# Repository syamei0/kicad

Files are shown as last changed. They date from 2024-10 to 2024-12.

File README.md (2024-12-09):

power_suplly_v3.1.0

⚠注意⚠　　
リレーの逆起電力対策がされていません。　　
ダイオードを外付けして使用してください。　　

入力は12V  
出力  
12V×7(合計20Aまで)  
5V×8(3.3V出力と合わせて合計1.5Aまで)  
3.3V×8(合計800mAまで)  

LEDの抵抗値変えたら24V入力もできるかも  
その場合12V系統は無くなるけど　　

左下のDIPスイッチで非常停止ボタン押したときに切る系統を変更可能  


パーツ
https://partscabi.net/list/3c4d911b-a046-48f9-8f62-2c7ad6c0e181

ESP32_SMD_v2.1.0  
esp32-wroom-32e用の基板です。

仕様　　  
・圧電スピーカーは0ピン　  
・CANはTXDが5ピン、RXDが4ピン　　  
・JP3とJP4はcanの終端抵抗　　  
・上バー付の数字はPWM可　　  
・白抜き文字は書き込み中プルアップ　　  

3D ビューアー 2024_12_01 20_32_58
パーツ(コンデンサー類未入力)
https://partscabi.net/list/7565f6eb-4755-48bc-bd06-0c08493c0ea4

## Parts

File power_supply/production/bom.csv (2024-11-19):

Designator | Footprint | Quantity | Value | LCSC Part #
C1 | CP_Radial_D10.0mm_P5.00mm | 1 | C_Polarized
C5, C7 | 0603 | 2 | 1μF
C6, C8 | 0603 | 2 | 0.1μF
D1, D2, D3 | 0603 | 3 | LED
D4 | 0603 | 1 | OSHR1608C1A
D5 | D_SOD-123F | 1 | GS1010FL
D6, D7, D8 | D_SOD-123F | 3 | D
F1, F2, F3, F4, F5, F6, F7 | 3557-15_KEY | 7 | Fuse
J1 | AMASS_XT60-M_1x02_P7.20mm_Vertical | 1 | XT60_IN
J10, J11, J12, J13, J14, J15, J16, J9 | JST_XH_B2B-XH-A_1x02_P2.50mm_Vertical | 8 | XH_OUT
J17, J18, J19, J20, J21, J22, J23, J24 | JST_XH_B2B-XH-A_1x02_P2.50mm_Vertical | 8 | XH_3.3V_OUT
J2 | JST_XH_B2B-XH-A_1x02_P2.50mm_Vertical | 1 | Emergency Stop Switch
J25, J3, J4, J5, J6, J7, J8 | AMASS_XT60-F_1x02_P7.20mm_Vertical | 7 | XT60_OUT
Q1 | TO-252-3_TabPin2 | 1 | TTC014
R1, R2, R3, R4, R6 | 0603 | 5 | 10kΩ
R5 | 0603 | 1 | 1kΩ
SW1 | KSD42 | 1 | SW_DIP_x04
U1 | TO-252-3_TabPin2 | 1 | NJM7805SDL1
U2 | TO-252-3_TabPin2 | 1 | NJM2845DL1-33
U3 | 953-1C-12DG-1 | 1 | 953-1C-12DG-1
U4, U5 | 134-1C-12DS | 2 | 134-1C-12DS

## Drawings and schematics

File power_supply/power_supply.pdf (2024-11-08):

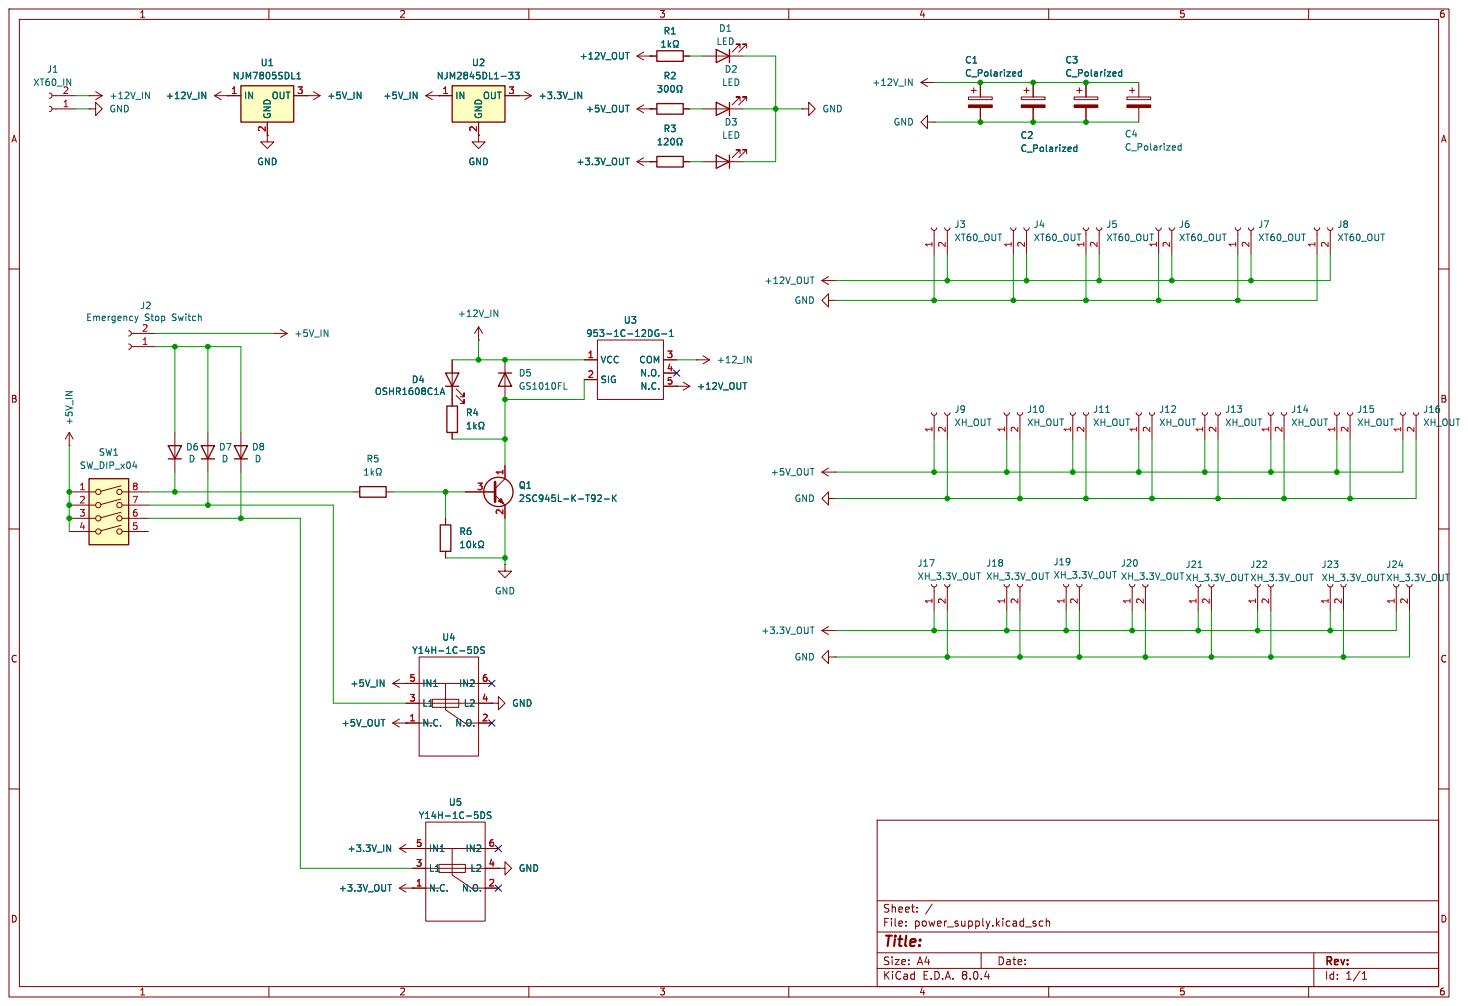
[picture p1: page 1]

Id: 1/1 Title: File: power_supply.kicad_sch Sheet: /

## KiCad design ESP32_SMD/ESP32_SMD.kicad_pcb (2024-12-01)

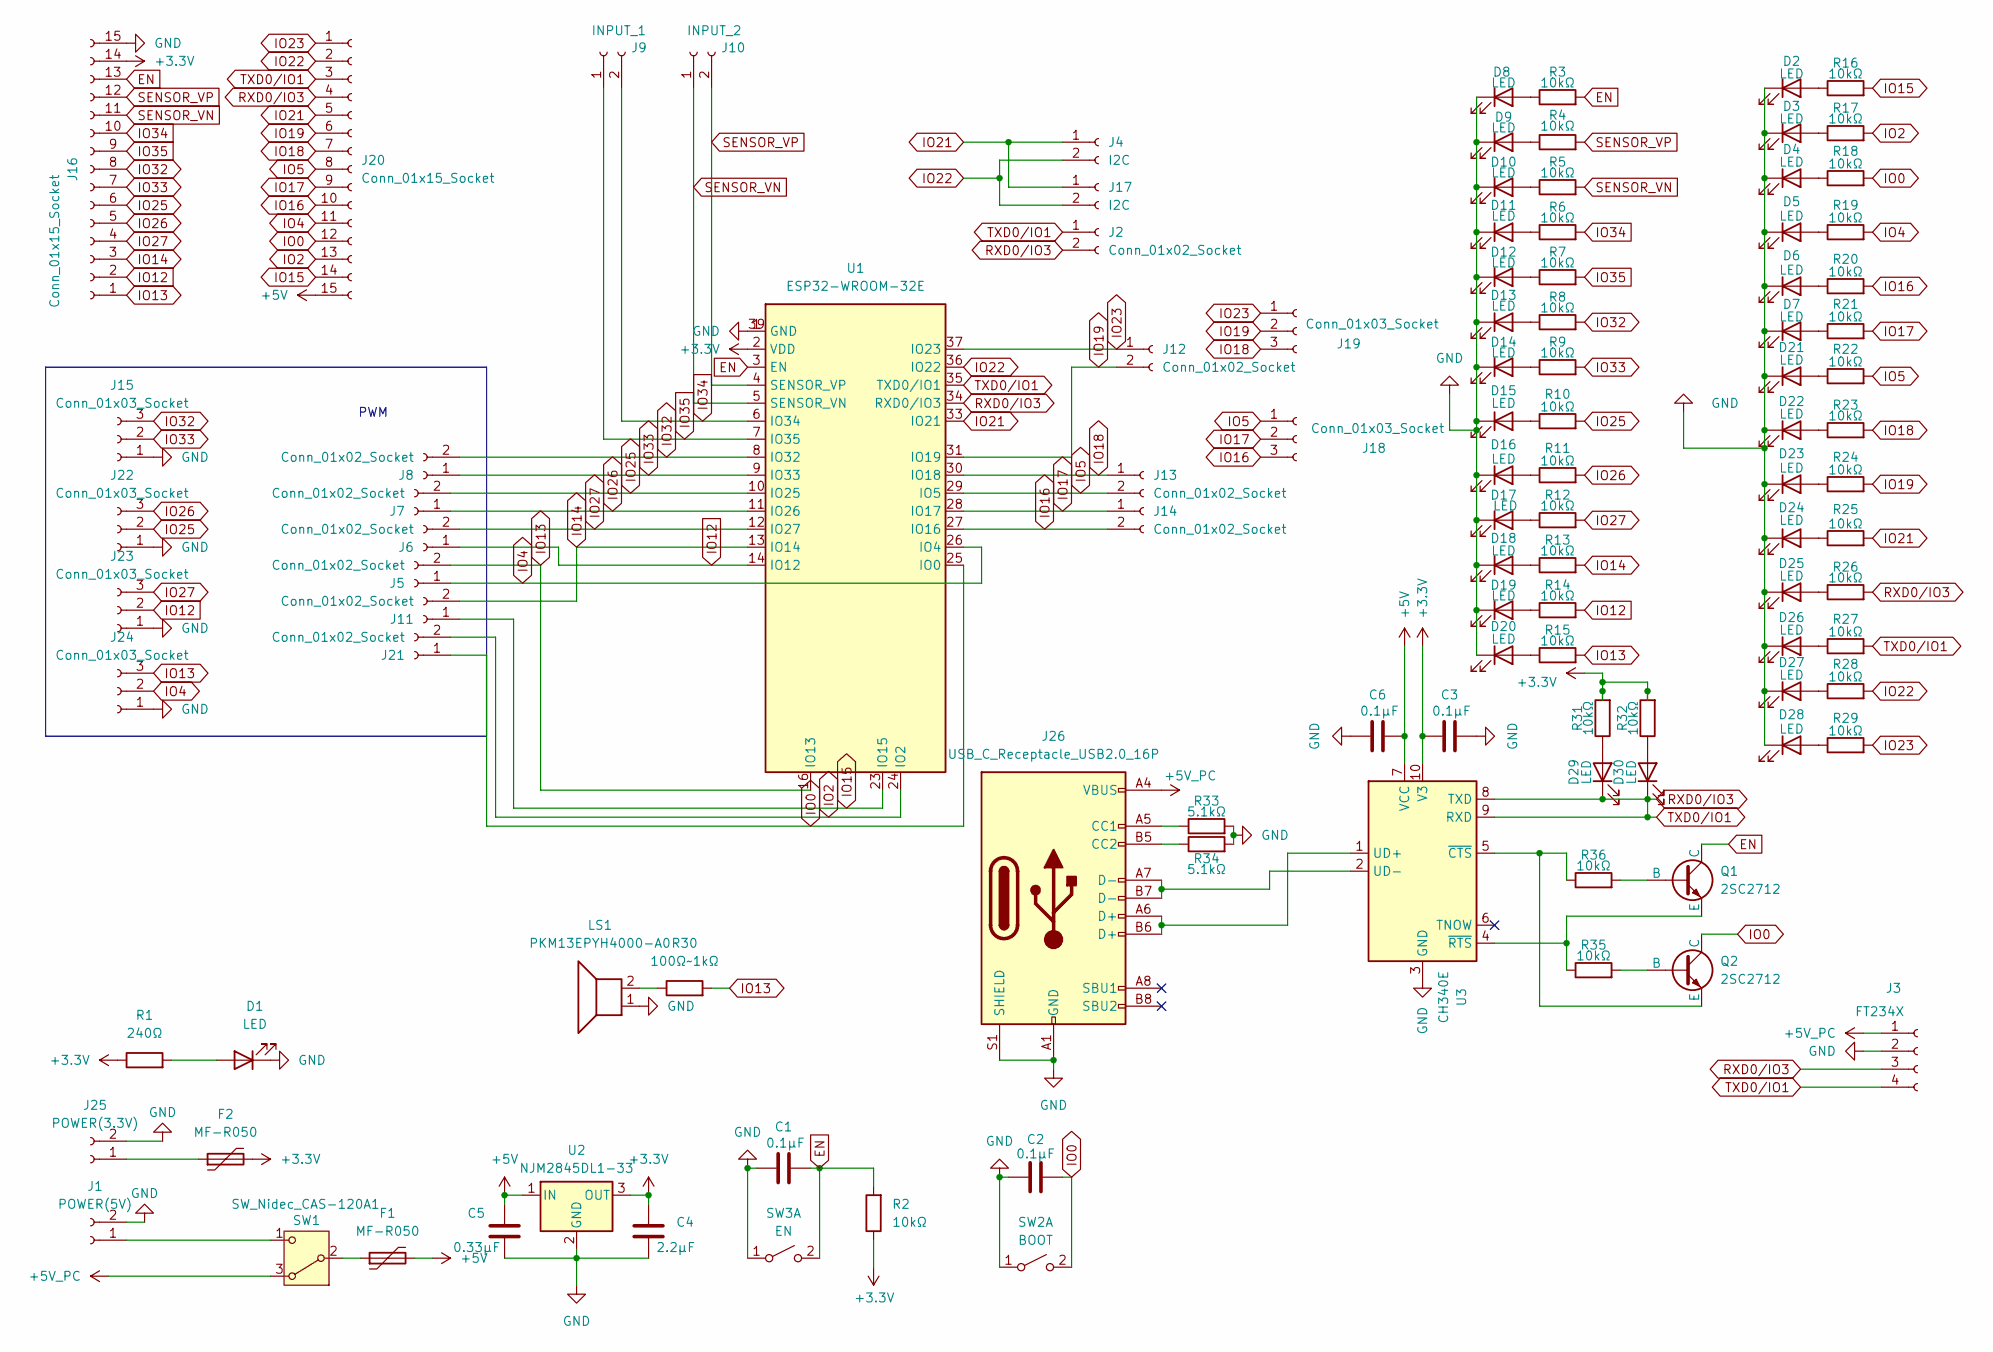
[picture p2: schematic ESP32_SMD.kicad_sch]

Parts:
C1, C2, C3, C6: 0.1μF; C_0603_1608Metric_Pad1.08x0.95mm_HandSolder
C4: 2.2μF; C_0603_1608Metric_Pad1.08x0.95mm_HandSolder
C5: 0.33μF; C_0603_1608Metric_Pad1.08x0.95mm_HandSolder
D1: LED; LED_0603_1608Metric
D2, D3, D4, D5, D6, D7, D8, D9, D10, D11, D12, D13, D14, D15, D16, D17, D18, D19, D20, D21, D22, D23, D24, D25, D26, D27, D28, D29, D30: LED; LED_0603_1608Metric_Pad1.05x0.95mm_HandSolder
F1, F2: MF-R050
J1: POWER(5V); JST_XH_B2B-XH-A_1x02_P2.50mm_Vertical
J2, J5, J6, J7, J8, J11, J12, J13, J14, J21: Conn_01x02_Socket; JST_XH_B2B-XH-A_1x02_P2.50mm_Vertical
J3: FT234X; PinHeader_1x04_P2.54mm_Vertical
J4, J17: I2C; JST_XH_B2B-XH-A_1x02_P2.50mm_Vertical
J9: INPUT_1; JST_XH_B2B-XH-A_1x02_P2.50mm_Vertical
J10: INPUT_2; JST_XH_B2B-XH-A_1x02_P2.50mm_Vertical
J15, J18, J19, J22, J23, J24: Conn_01x03_Socket; JST_XH_B3B-XH-A_1x03_P2.50mm_Vertical
J16, J20: Conn_01x15_Socket; PinHeader_1x15_P2.54mm_Vertical
J25: POWER(3.3V); JST_XH_B2B-XH-A_1x02_P2.50mm_Vertical
J26: USB_C_Receptacle_USB2.0_16P; USB_C_Receptacle_GCT_USB4105-xx-A_16P_TopMnt_Horizontal
LS1: PKM13EPYH4000-A0
Q1, Q2: 2SC2712; SOT-23
R1: 240Ω; R_0603_1608Metric_Pad0.98x0.95mm_HandSolder
R2, R3, R4, R5, R6, R7, R8, R9, R10, R11, R12, R13, R14, R15, R16, R17, R18, R19, R20, R21, R22, R23, R24, R25, R26, R27, R28, R29, R31, R32, R35, R36: 10kΩ; R_0603_1608Metric_Pad0.98x0.95mm_HandSolder
R30: 100Ω~1kΩ; R_0603_1608Metric_Pad0.98x0.95mm_HandSolder
R33, R34: 5.1kΩ; R_0603_1608Metric_Pad0.98x0.95mm_HandSolder
SW1: SW_Nidec_CAS-120A1; TerminalBlock_Xinya_XY308-2.54-3P_1x03_P2.54mm_Horizontal
SW2: BOOT; DTS-63-N-V
SW3: EN; DTS-63-N-V
U1: ESP32-WROOM-32E
U2: NJM2845DL1-33; TO-252-3_TabPin2
U3: CH340E; MSOP-10_3x3mm_P0.5mm

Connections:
+3.3V: C3.2, C4.2, F2.2, J16.14, R1.1, R2.1, R31.2, R32.2, U1.2 (VDD), U2.3 (OUT), U3.10 (V3)
+5V: C5.2, C6.1, F1.2, J20.15, U2.1 (IN), U3.7 (VCC)
+5V_PC: J3.1 (5V), J26.A4 (VBUS), J26.A9 (VBUS), J26.B4 (VBUS), J26.B9 (VBUS), SW1.3 (A)
EN: C1.1, J16.13, Q1.1 (C), R2.2, R3.2, SW3.2 (B), U1.3 (EN)
GND: C1.2, C2.2, C3.1, C4.1, C5.1, C6.2, D1.1 (K), D2.1 (K), D3.1 (K), D4.1 (K), D5.1 (K), D6.1 (K), D7.1 (K), D8.1 (K), D9.1 (K), D10.1 (K), D11.1 (K), D12.1 (K), D13.1 (K), D14.1 (K), D15.1 (K), D16.1 (K), D17.1 (K), D18.1 (K), D19.1 (K), D20.1 (K), D21.1 (K), D22.1 (K), D23.1 (K), D24.1 (K), D25.1 (K), D26.1 (K), D27.1 (K), D28.1 (K), J1.2, J3.2 (GND), J15.1, J16.15, J22.1, J23.1, J24.1, J25.2, J26.A1 (GND), J26.A12 (GND), J26.B1 (GND), J26.B12 (GND), J26.S1 (SHIELD), LS1.1, R33.2, R34.2, SW2.1 (A), SW3.1 (A), U1.1 (GND), U1.15 (GND), U1.38 (GND), U1.39 (GND), U2.2 (GND), U3.3 (GND)
IO0: C2.1, J20.12, J21.1, Q2.1 (C), R18.2, SW2.2 (B), U1.25 (IO0)
IO2: J20.13, J21.2, R17.2, U1.24 (IO2)
IO4: J5.1, J20.11, J24.2, R19.2, U1.26 (IO4)
IO5: J13.2, J18.1, J20.8, R22.2, U1.29 (IO5)
IO12: J6.1, J16.2, J23.2, R14.2, U1.14 (IO12)
IO13: J5.2, J16.1, J24.3, R15.2, R30.2, U1.16 (IO13)
IO14: J11.2, J16.3, R13.2, U1.13 (IO14)
IO15: J11.1, J20.14, R16.2, U1.23 (IO15)
IO16: J14.2, J18.3, J20.10, R20.2, U1.27 (IO16)
IO17: J14.1, J18.2, J20.9, R21.2, U1.28 (IO17)
IO18: J13.1, J19.3, J20.7, R23.2, U1.30 (IO18)
IO19: J12.2, J19.2, J20.6, R24.2, U1.31 (IO19)
IO21: J4.1, J17.1, J20.5, R25.2, U1.33 (IO21)
IO22: J4.2, J17.2, J20.2, R28.2, U1.36 (IO22)
IO23: J12.1, J19.1, J20.1, R29.2, U1.37 (IO23)
IO25: J7.2, J16.6, J22.2, R10.2, U1.10 (IO25)
IO26: J7.1, J16.5, J22.3, R11.2, U1.11 (IO26)
IO27: J6.2, J16.4, J23.3, R12.2, U1.12 (IO27)
IO32: J8.2, J15.3, J16.8, R8.2, U1.8 (IO32)
IO33: J8.1, J15.2, J16.7, R9.2, U1.9 (IO33)
IO34: J9.2, J16.10, R6.2, U1.6 (IO34)
IO35: J9.1, J16.9, R7.2, U1.7 (IO35)
unnamed: D1.2 (A), R1.2
unnamed: D2.2 (A), R16.1
unnamed: D3.2 (A), R17.1
unnamed: D4.2 (A), R18.1
unnamed: D5.2 (A), R19.1
unnamed: D6.2 (A), R20.1
unnamed: D7.2 (A), R21.1
unnamed: D8.2 (A), R3.1
unnamed: D9.2 (A), R4.1
unnamed: D10.2 (A), R5.1
unnamed: D11.2 (A), R6.1
unnamed: D12.2 (A), R7.1
unnamed: D13.2 (A), R8.1
unnamed: D14.2 (A), R9.1
unnamed: D15.2 (A), R10.1
unnamed: D16.2 (A), R11.1
unnamed: D17.2 (A), R12.1
unnamed: D18.2 (A), R13.1
unnamed: D19.2 (A), R14.1
unnamed: D20.2 (A), R15.1
unnamed: D21.2 (A), R22.1
unnamed: D22.2 (A), R23.1
unnamed: D23.2 (A), R24.1
unnamed: D24.2 (A), R25.1
unnamed: D25.2 (A), R26.1
unnamed: D26.2 (A), R27.1
unnamed: D27.2 (A), R28.1
unnamed: D28.2 (A), R29.1
unnamed: D29.2 (A), R31.1
unnamed: D30.2 (A), R32.1
unnamed: J1.1, SW1.1 (C)
unnamed: F2.1, J25.1
unnamed: J26.A5 (CC1), R33.1
unnamed: J26.B5 (CC2), R34.1
unnamed: LS1.2, R30.1
unnamed: Q1.2 (B), R36.2
unnamed: Q1.3 (E), R35.1, U3.4 (~RTS)
unnamed: Q2.2 (B), R35.2
unnamed: Q2.3 (E), R36.1, U3.5 (~CTS)
unnamed: F1.1, SW1.2 (B)
unnamed: J26.A6 (D+), J26.B6 (D+), U3.1 (UD+)
unnamed: J26.A7 (D-), J26.B7 (D-), U3.2 (UD-)
RXD0/IO3: D29.1 (K), D30.1 (K), J2.1, J2.2, J3.3 (TxD), J3.4 (RxD), J20.3, J20.4, R26.2, R27.2, U1.34 (RXD0/IO3), U1.35 (TXD0/IO1), U3.8 (TXD), U3.9 (RXD)
SENSOR_VN: J10.1, J16.11, R5.2, U1.5 (SENSOR_VN)
SENSOR_VP: J10.2, J16.12, R4.2, U1.4 (SENSOR_VP)

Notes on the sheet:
PWM

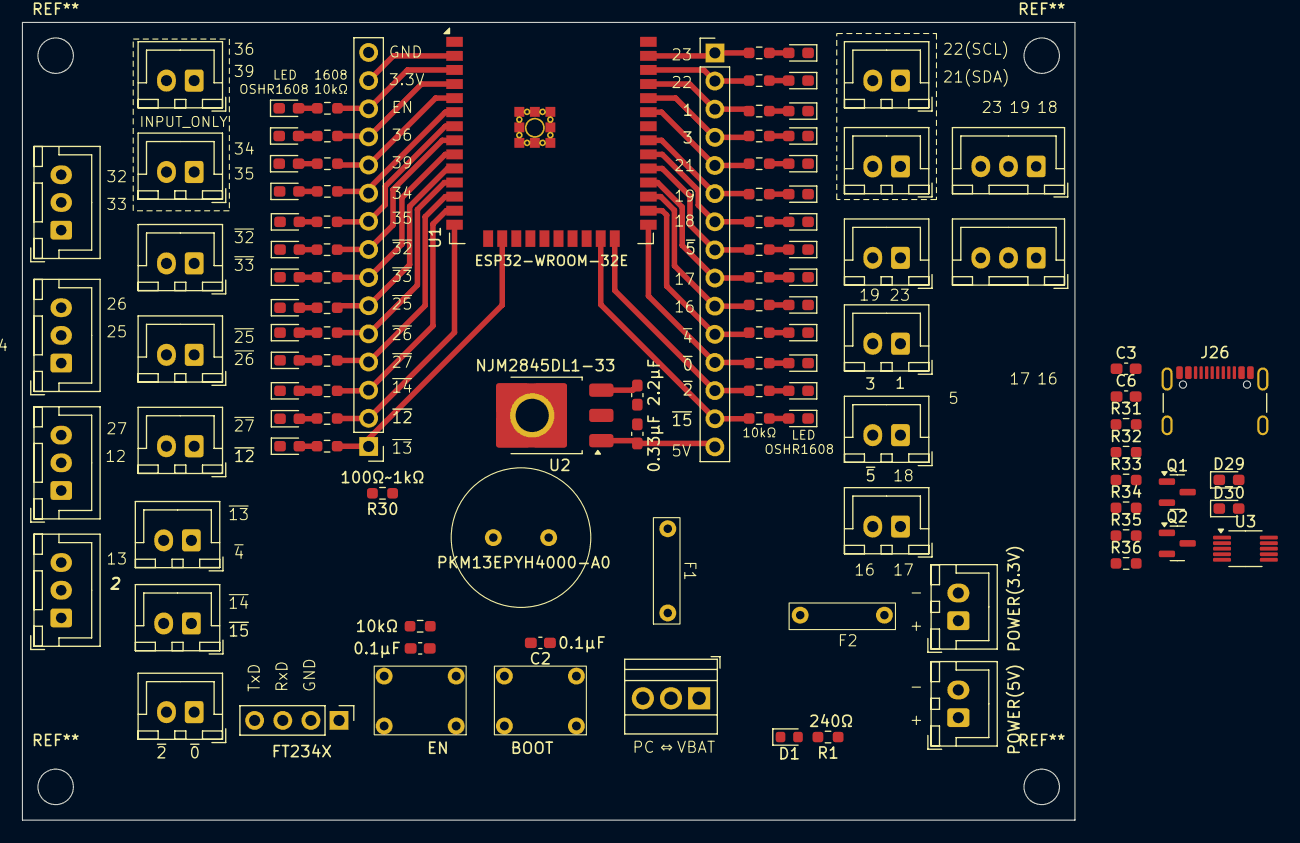
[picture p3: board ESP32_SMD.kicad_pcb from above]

Board: 2 copper layers, 95.0 x 72.0 mm, 109 parts (0 on the bottom side), 72 nets.

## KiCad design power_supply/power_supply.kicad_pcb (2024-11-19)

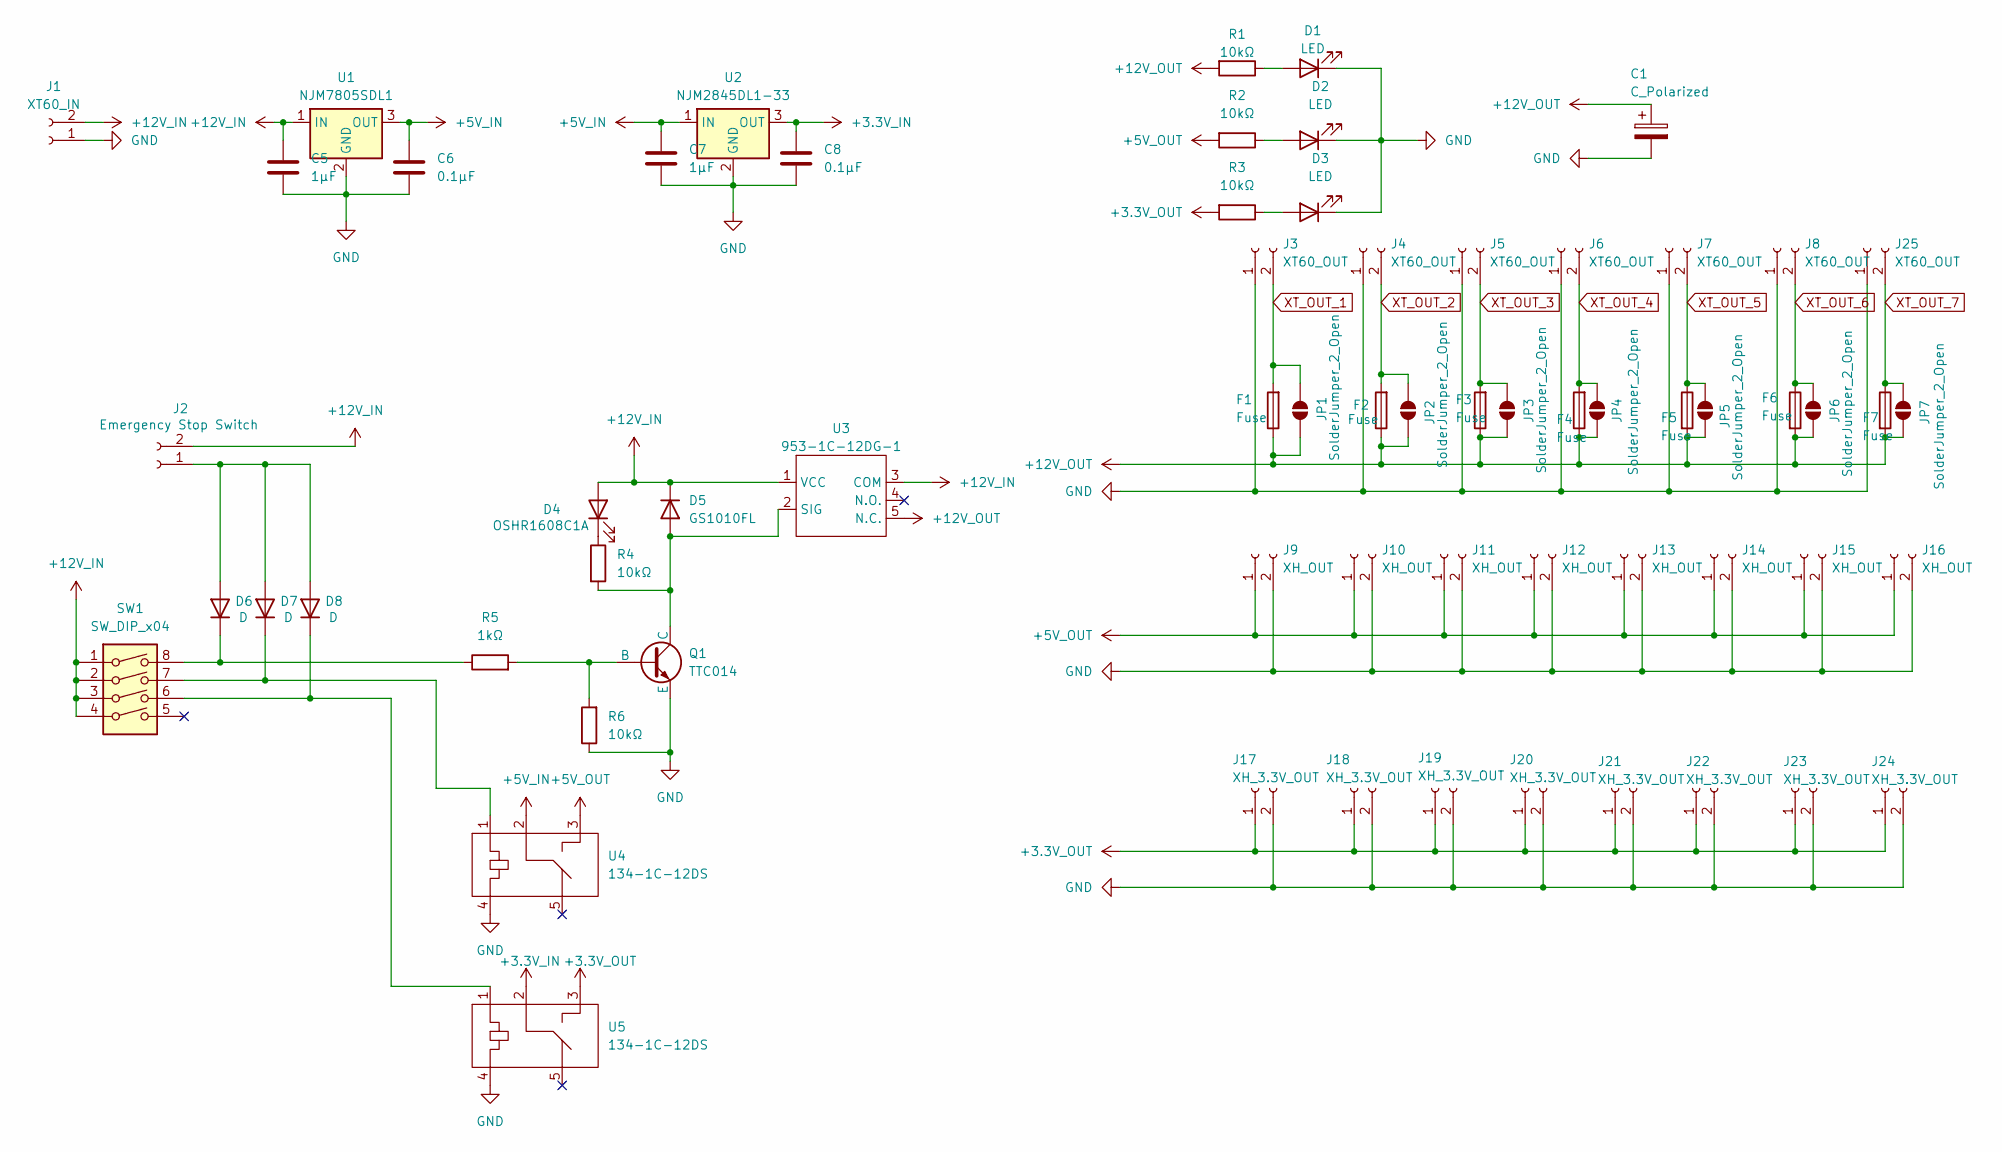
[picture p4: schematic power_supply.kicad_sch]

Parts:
C1: C_Polarized; CP_Radial_D10.0mm_P5.00mm
C5, C7: 1μF; C_0603_1608Metric_Pad1.08x0.95mm_HandSolder
C6, C8: 0.1μF; C_0603_1608Metric_Pad1.08x0.95mm_HandSolder
D1, D2, D3: LED; LED_0603_1608Metric_Pad1.05x0.95mm_HandSolder
D4: OSHR1608C1A; LED_0603_1608Metric_Pad1.05x0.95mm_HandSolder
D5: GS1010FL; D_SOD-123F
D6, D7, D8: D; D_SOD-123F
F1, F2, F3, F4, F5, F6, F7: Fuse; 3557-15_KEY
J1: XT60_IN; AMASS_XT60-M_1x02_P7.20mm_Vertical
J2: Emergency Stop Switch; JST_XH_B2B-XH-A_1x02_P2.50mm_Vertical
J3, J4, J5, J6, J7, J8, J25: XT60_OUT; AMASS_XT60-F_1x02_P7.20mm_Vertical
J9, J10, J11, J12, J13, J14, J15, J16: XH_OUT; JST_XH_B2B-XH-A_1x02_P2.50mm_Vertical
J17, J18, J19, J20, J21, J22, J23, J24: XH_3.3V_OUT; JST_XH_B2B-XH-A_1x02_P2.50mm_Vertical
JP1, JP2, JP3, JP4, JP5, JP6, JP7: SolderJumper_2_Open; SolderJumper-2_P1.3mm_Open_Pad1.0x1.5mm
Q1: TTC014; TO-252-3_TabPin2
R1, R2, R3, R4, R6: 10kΩ; R_0603_1608Metric_Pad0.98x0.95mm_HandSolder
R5: 1kΩ; R_0603_1608Metric_Pad0.98x0.95mm_HandSolder
SW1: SW_DIP_x04; KSD42
U1: NJM7805SDL1; TO-252-3_TabPin2
U2: NJM2845DL1-33; TO-252-3_TabPin2
U3: 953-1C-12DG-1
U4, U5: 134-1C-12DS

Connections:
+3.3V_IN: C8.1, U2.3 (OUT), U5.2
+3.3V_OUT: J17.1, J18.1, J19.1, J20.1, J21.1, J22.1, J23.1, J24.1, R3.2, U5.3
+5V_IN: C6.1, C7.1, U1.3 (OUT), U2.1 (IN), U4.2
+5V_OUT: J9.1, J10.1, J11.1, J12.1, J13.1, J14.1, J15.1, J16.1, R2.2, U4.3
+12V_IN: C5.1, D4.2 (A), D5.1 (K), J1.2, J2.2, SW1.1, SW1.2, SW1.3, SW1.4, U1.1 (IN), U3.1 (VCC), U3.3 (COM)
+12V_OUT: C1.1, F1.1, F2.1, F3.1, F4.1, F5.2, F6.2, F7.2, JP1.1 (A), JP2.1 (A), JP3.1 (A), JP4.1 (A), JP5.1 (A), JP6.1 (A), JP7.1 (A), R1.2, U3.5 (N.C.)
GND: C1.2, C5.2, C6.2, C7.2, C8.2, D1.1 (K), D2.1 (K), D3.1 (K), J1.1, J3.1, J4.1, J5.1, J6.1, J7.1, J8.1, J9.2, J10.2, J11.2, J12.2, J13.2, J14.2, J15.2, J16.2, J17.2, J18.2, J19.2, J20.2, J21.2, J22.2, J23.2, J24.2, J25.1, Q1.3 (E), R6.1, U1.2 (GND), U2.2 (GND), U4.4, U5.4
unnamed: D1.2 (A), R1.1
unnamed: D2.2 (A), R2.1
unnamed: D3.2 (A), R3.1
unnamed: D4.1 (K), R4.1
unnamed: D5.2 (A), Q1.2 (C), R4.2, U3.2 (SIG)
unnamed: D6.2 (A), D7.2 (A), D8.2 (A), J2.1
unnamed: D6.1 (K), R5.1, SW1.8
unnamed: D7.1 (K), SW1.7, U4.1
unnamed: D8.1 (K), SW1.6, U5.1
unnamed: Q1.1 (B), R5.2, R6.2
XT_OUT_1: F1.2, J3.2, JP1.2 (B)
XT_OUT_2: F2.2, J4.2, JP2.2 (B)
XT_OUT_3: F3.2, J5.2, JP3.2 (B)
XT_OUT_4: F4.2, J6.2, JP4.2 (B)
XT_OUT_5: F5.1, J7.2, JP5.2 (B)
XT_OUT_6: F6.1, J8.2, JP6.2 (B)
XT_OUT_7: F7.1, J25.2, JP7.2 (B)

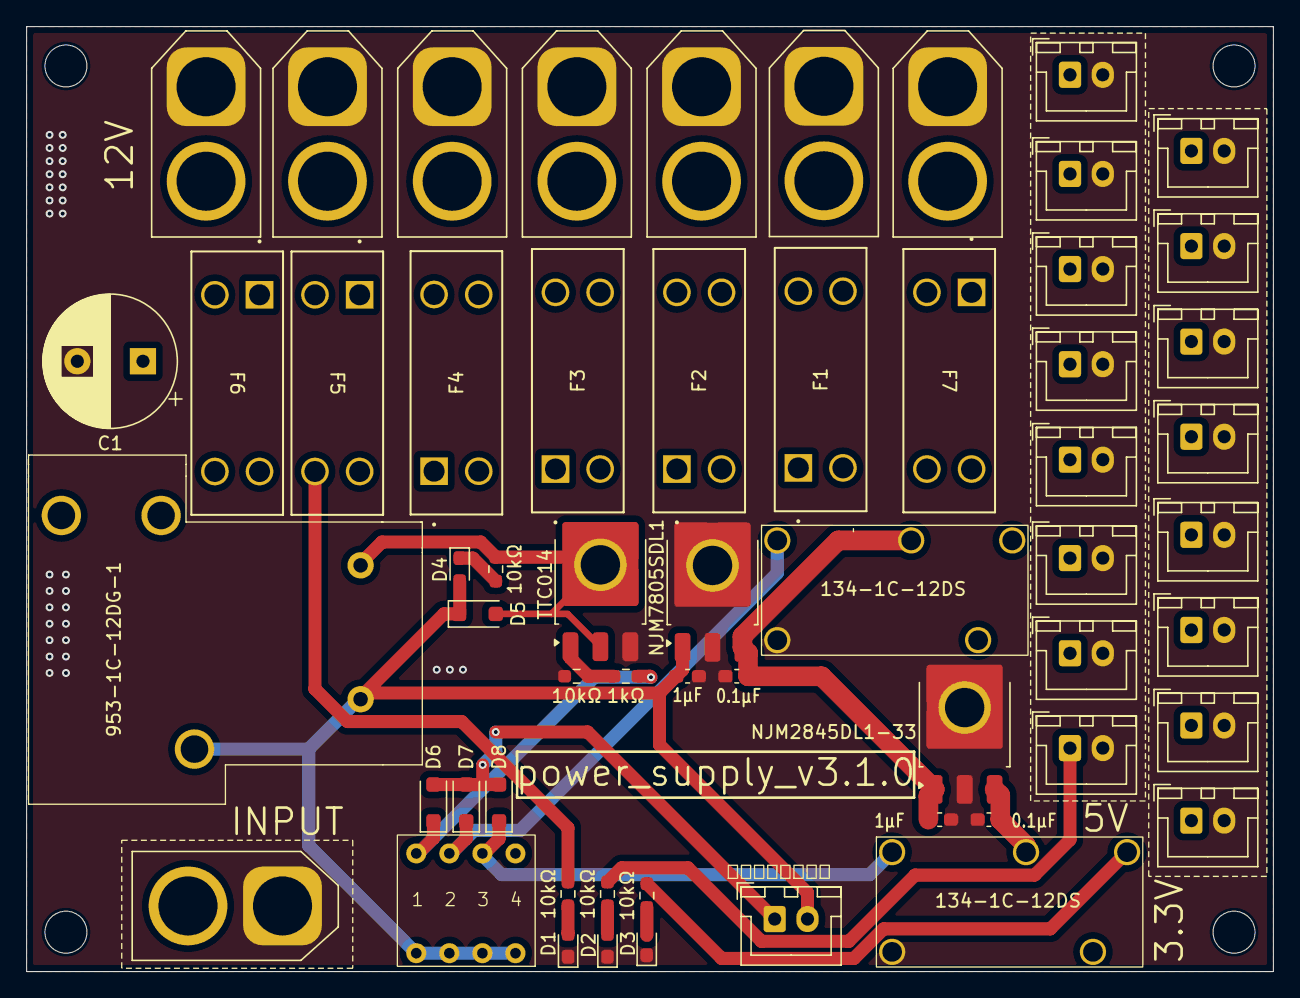
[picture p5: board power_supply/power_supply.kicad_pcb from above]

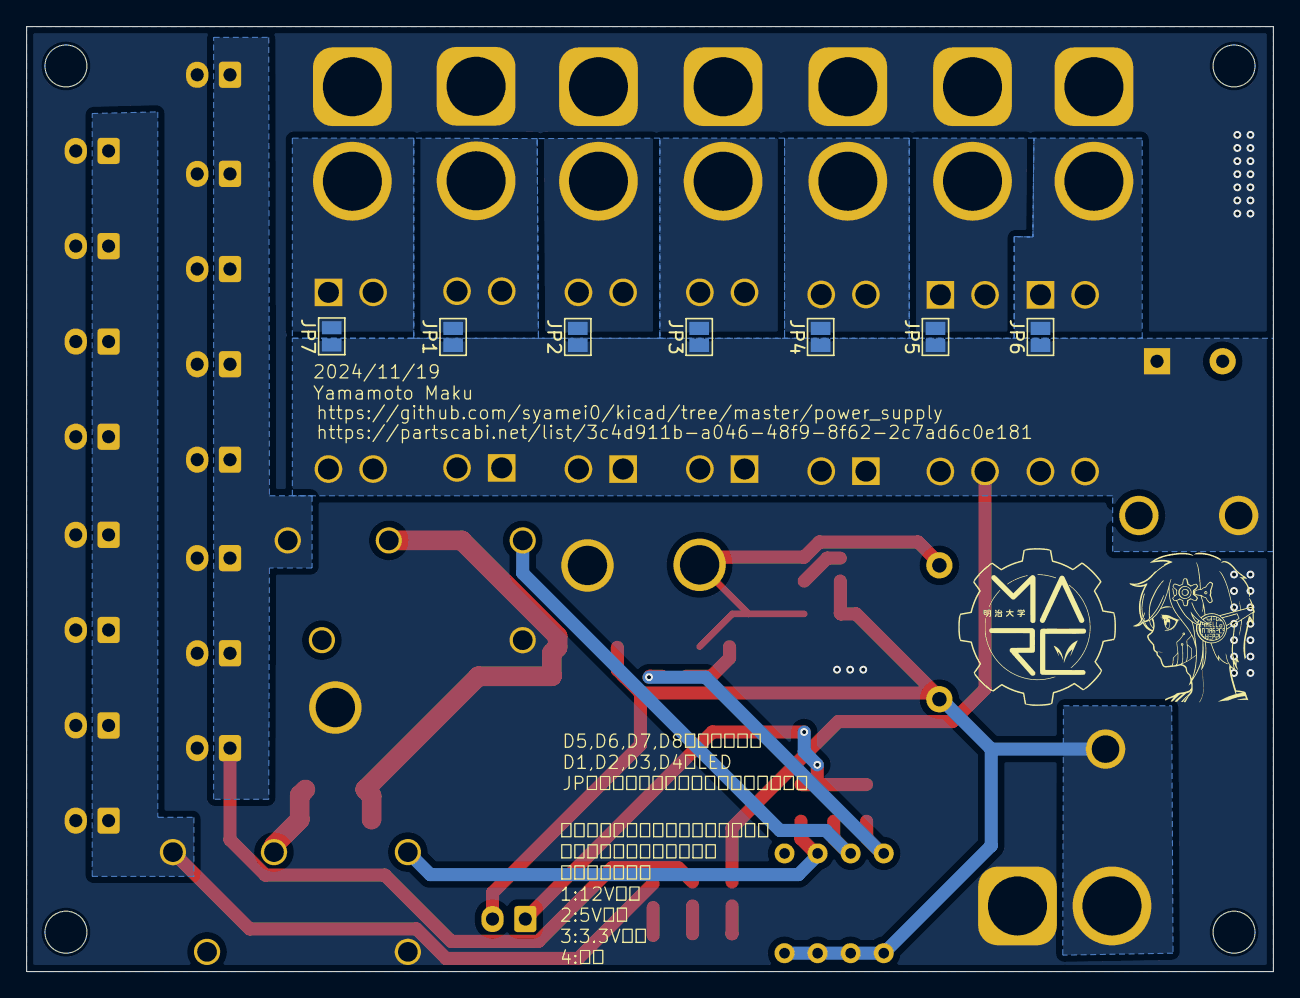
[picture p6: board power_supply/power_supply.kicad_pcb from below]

Board: 2 copper layers, 95.0 x 72.0 mm, 65 parts (7 on the bottom side), 24 nets.

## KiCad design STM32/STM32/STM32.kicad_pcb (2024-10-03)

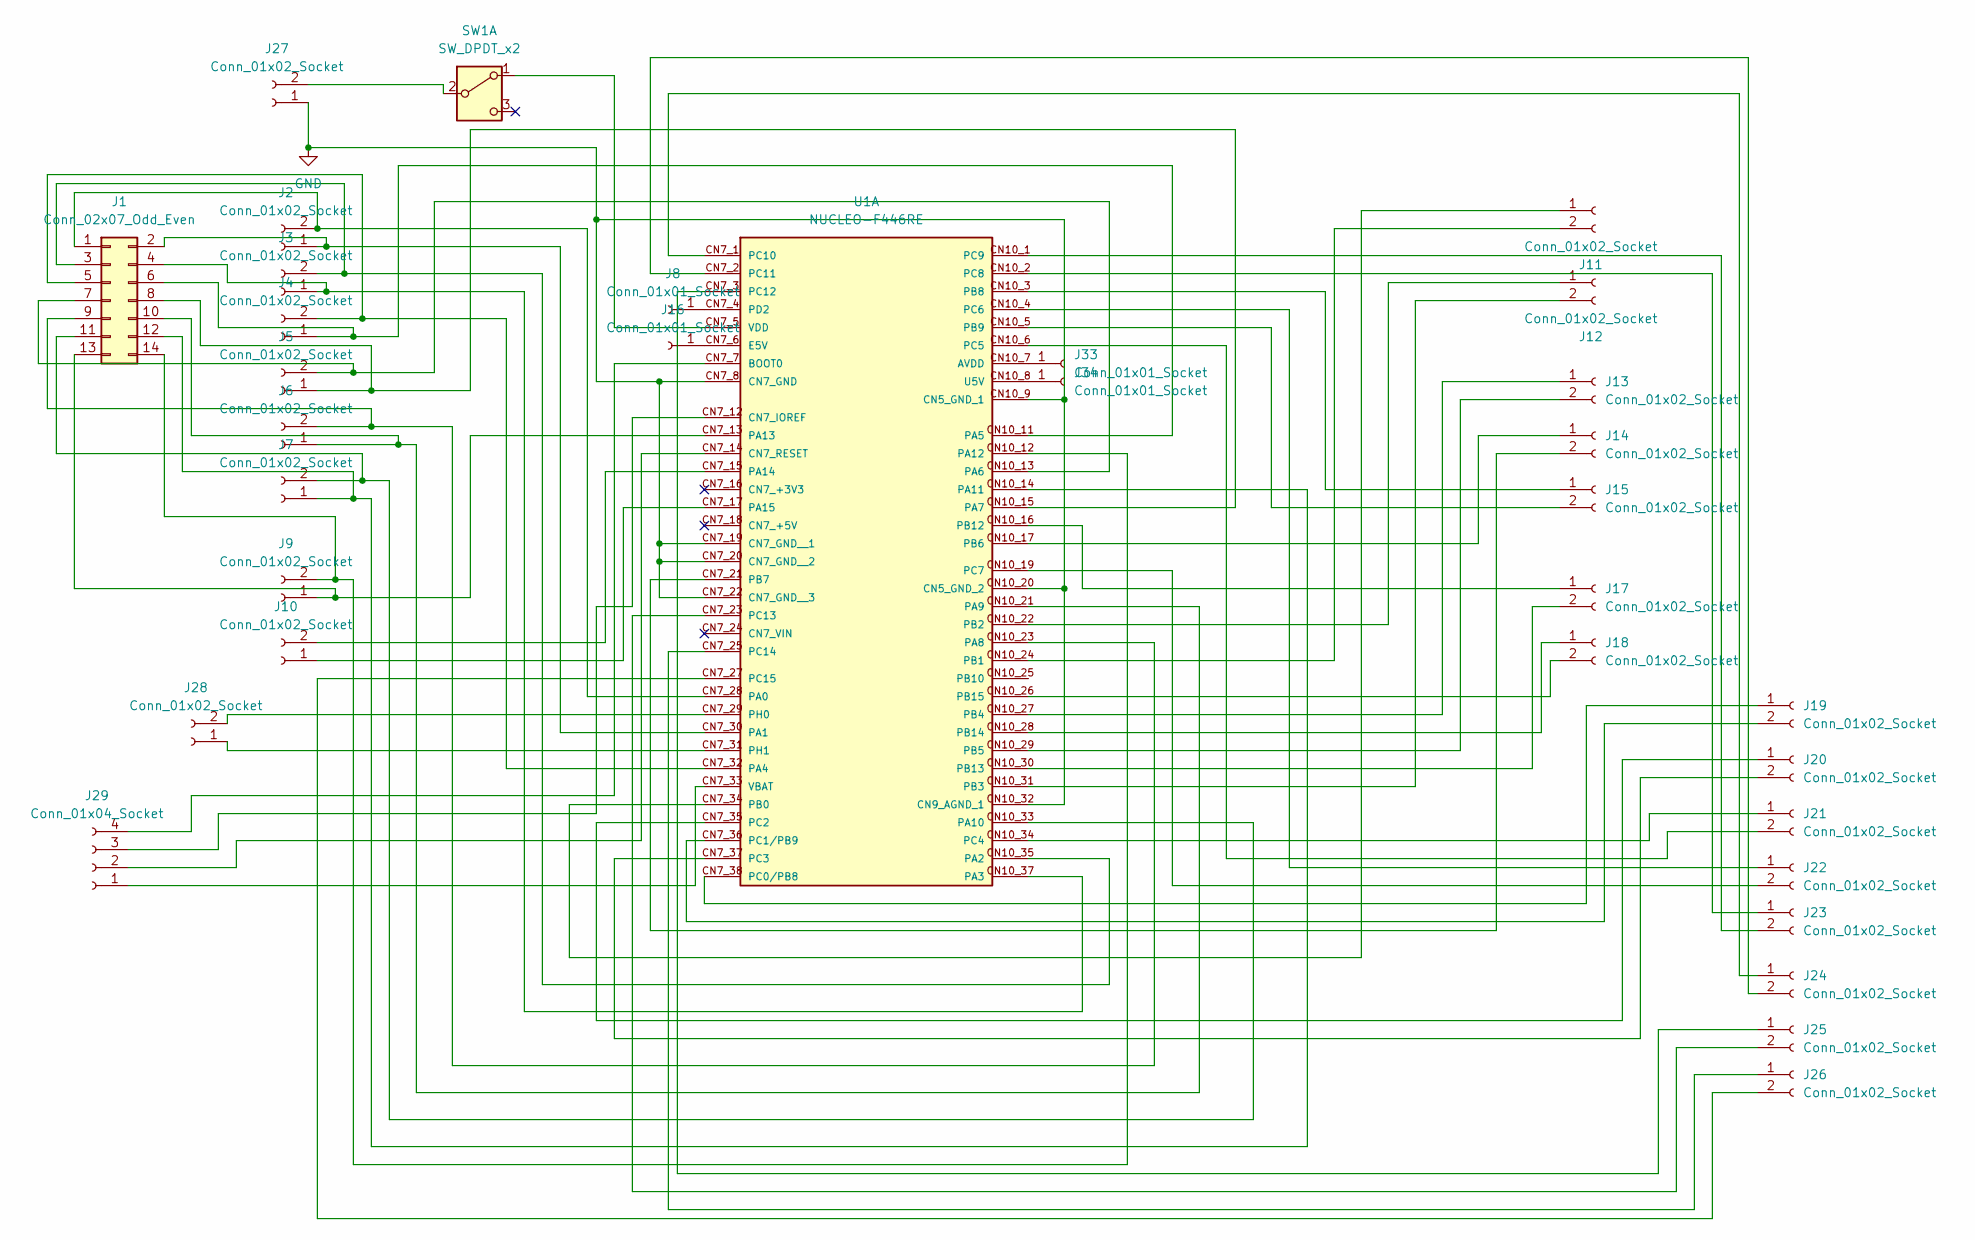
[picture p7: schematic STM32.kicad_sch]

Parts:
J1: Conn_02x07_Odd_Even; PinHeader_2x07_P2.54mm_Vertical
J2, J3, J4, J5, J6, J7, J9, J10, J11, J12, J13, J14, J15, J17, J18, J19, J20, J21, J22, J23, J24, J25, J26, J27, J28: Conn_01x02_Socket; JST_XH_B2B-XH-AM_1x02_P2.50mm_Vertical
J8, J16, J33, J34: Conn_01x01_Socket; JST_XH_B1B-XH-AM_1x01_P2.50mm_Vertical
J29: Conn_01x04_Socket; JST_XH_B4B-XH-AM_1x04_P2.50mm_Vertical
SW1: SW_DPDT_x2; PinHeader_1x03_P2.54mm_Vertical
U1: NUCLEO-F446RE; MODULE_NUCLEO-F446RE; PARTREV 13

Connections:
GND: J27.1, U1.CN7_8 (CN7_GND), U1.CN7_19 (CN7_GND__1), U1.CN7_20 (CN7_GND__2), U1.CN7_22 (CN7_GND__3), U1.CN10_9 (CN5_GND_1), U1.CN10_20 (CN5_GND_2), U1.CN10_32 (CN9_AGND_1)
unnamed: J1.1, J2.2, U1.CN7_28 (PA0)
unnamed: J1.2, J2.1, U1.CN7_30 (PA1)
unnamed: J1.3, J3.2, U1.CN10_35 (PA2)
unnamed: J1.4, J3.1, U1.CN10_37 (PA3)
unnamed: J1.5, J4.2, U1.CN7_32 (PA4)
unnamed: J1.6, J4.1, U1.CN10_11 (PA5)
unnamed: J1.7, J5.2, U1.CN10_13 (PA6)
unnamed: J1.8, J5.1, U1.CN10_15 (PA7)
unnamed: J1.9, J6.2, U1.CN10_23 (PA8)
unnamed: J1.10, J6.1, U1.CN10_21 (PA9)
unnamed: J1.11, J7.2, U1.CN10_33 (PA10)
unnamed: J1.12, J7.1, U1.CN10_14 (PA11)
unnamed: J1.13, J9.1, U1.CN7_13 (PA13)
unnamed: J1.14, J9.2, U1.CN10_12 (PA12)
unnamed: J8.1, U1.CN7_4 (PD2)
unnamed: J10.1, U1.CN7_17 (PA15)
unnamed: J10.2, U1.CN7_15 (PA14)
unnamed: J11.1, U1.CN7_34 (PB0)
unnamed: J11.2, U1.CN10_24 (PB1)
unnamed: J12.1, U1.CN10_22 (PB2)
unnamed: J12.2, U1.CN10_31 (PB3)
unnamed: J13.1, U1.CN10_27 (PB4)
unnamed: J13.2, U1.CN10_29 (PB5)
unnamed: J14.1, U1.CN10_17 (PB6)
unnamed: J14.2, U1.CN7_21 (PB7)
unnamed: J15.1, U1.CN10_3 (PB8)
unnamed: J15.2, U1.CN10_5 (PB9)
unnamed: J16.1, U1.CN7_6 (E5V)
unnamed: J17.1, U1.CN10_16 (PB12)
unnamed: J17.2, U1.CN10_30 (PB13)
unnamed: J18.1, U1.CN10_28 (PB14)
unnamed: J18.2, U1.CN10_26 (PB15)
unnamed: J19.1, U1.CN7_38 (PC0/PB8)
unnamed: J19.2, U1.CN7_36 (PC1/PB9)
unnamed: J20.1, U1.CN7_35 (PC2)
unnamed: J20.2, U1.CN7_37 (PC3)
unnamed: J21.1, U1.CN10_34 (PC4)
unnamed: J21.2, U1.CN10_6 (PC5)
unnamed: J22.1, U1.CN10_4 (PC6)
unnamed: J22.2, U1.CN10_19 (PC7)
unnamed: J23.1, U1.CN10_2 (PC8)
unnamed: J23.2, U1.CN10_1 (PC9)
unnamed: J24.1, U1.CN7_1 (PC10)
unnamed: J24.2, U1.CN7_2 (PC11)
unnamed: J25.1, U1.CN7_3 (PC12)
unnamed: J25.2, U1.CN7_23 (PC13)
unnamed: J26.1, U1.CN7_25 (PC14)
unnamed: J26.2, U1.CN7_27 (PC15)
unnamed: J27.2, SW1.2 (B)
unnamed: J28.1, U1.CN7_31 (PH1)
unnamed: J28.2, U1.CN7_29 (PH0)
unnamed: J29.1, U1.CN7_33 (VBAT)
unnamed: J29.2, U1.CN7_14 (CN7_RESET)
unnamed: J29.3, U1.CN7_12 (CN7_IOREF)
unnamed: J29.4, U1.CN7_7 (BOOT0)
unnamed: J33.1, U1.CN10_7 (AVDD)
unnamed: J34.1, U1.CN10_8 (U5V)
unnamed: SW1.1 (A), U1.CN7_5 (VDD)

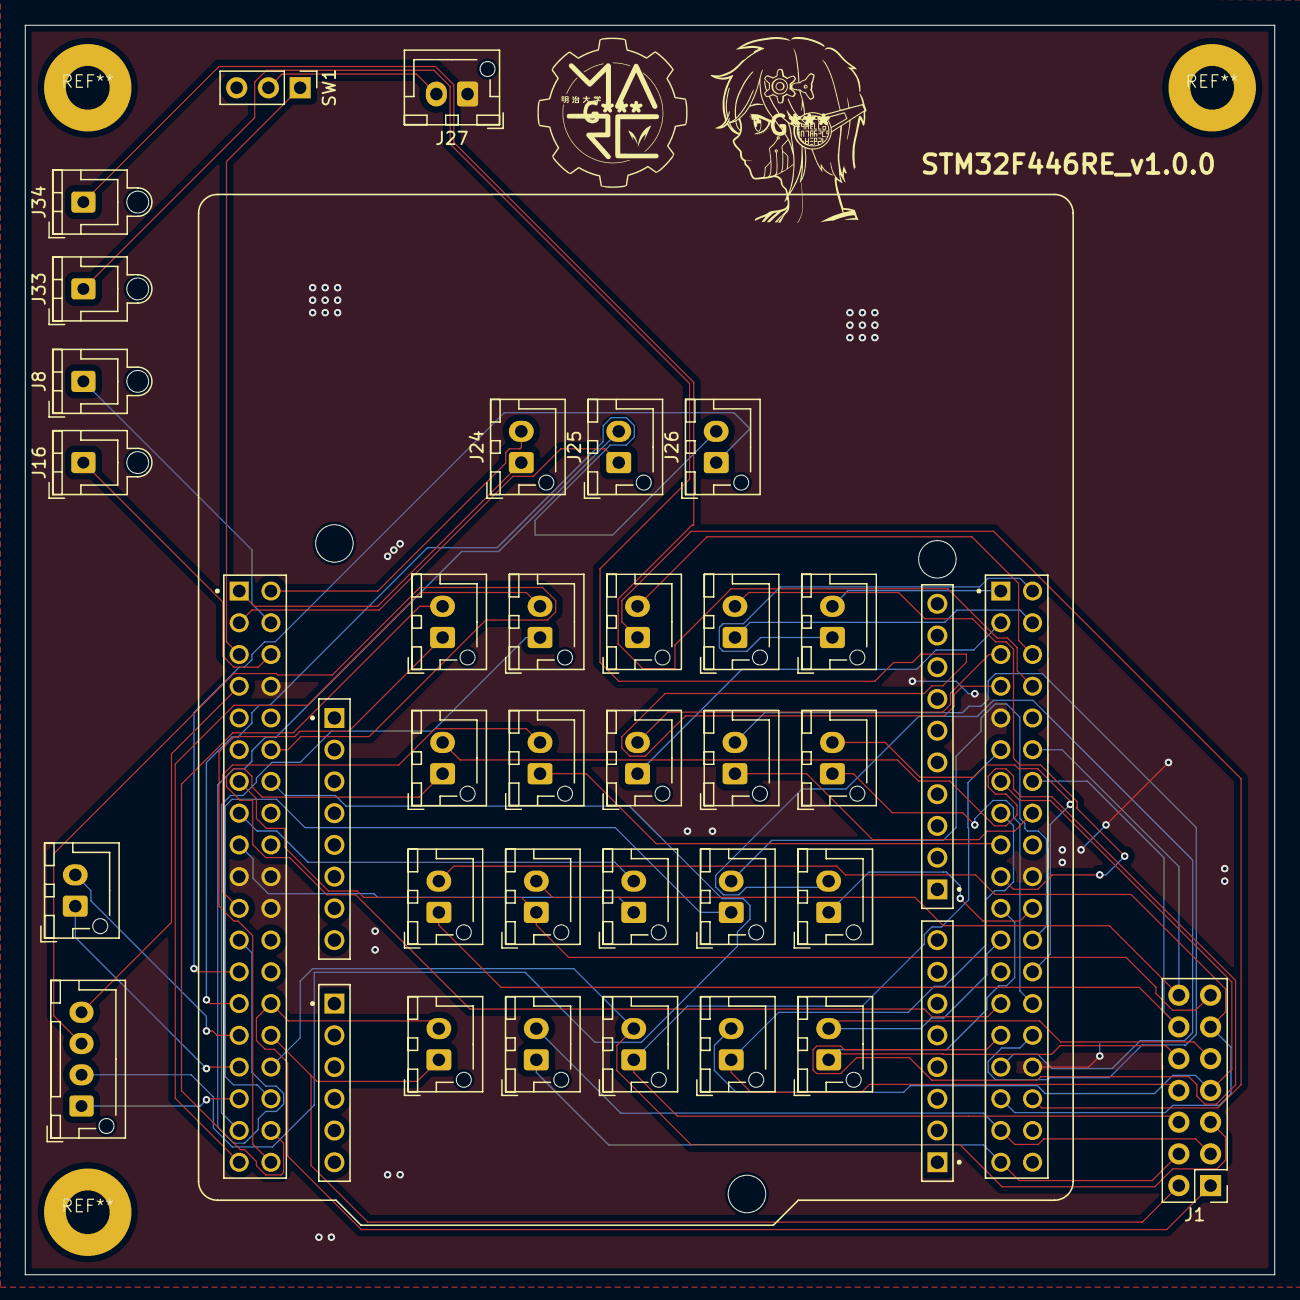
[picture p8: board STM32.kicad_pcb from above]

Board: 2 copper layers, 100.0 x 100.0 mm, 33 parts (0 on the bottom side), 59 nets.

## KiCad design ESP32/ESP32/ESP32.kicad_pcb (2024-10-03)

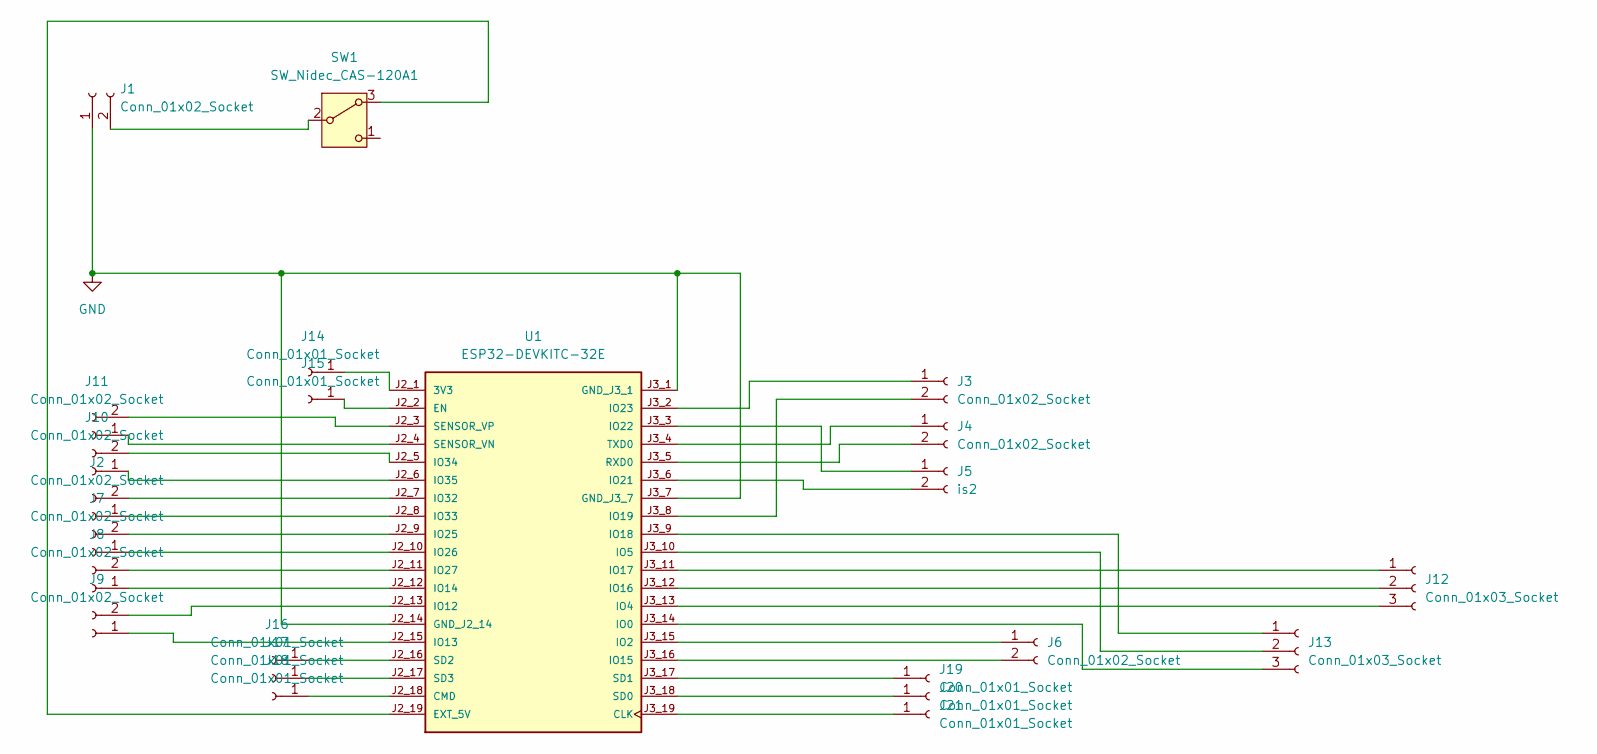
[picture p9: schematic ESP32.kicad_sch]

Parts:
J1: Conn_01x02_Socket; JST_XH_B2B-XH-AM_1x02_P2.50mm_Vertical
J2, J3, J4, J6, J7, J8, J9, J10, J11: Conn_01x02_Socket; JST_EH_B2B-EH-A_1x02_P2.50mm_Vertical
J5: is2; JST_EH_B2B-EH-A_1x02_P2.50mm_Vertical
J12, J13: Conn_01x03_Socket; JST_EH_B3B-EH-A_1x03_P2.50mm_Vertical
J14, J15, J16, J17, J18, J19, J20, J21: Conn_01x01_Socket; JST_XH_B1B-XH-AM_1x01_P2.50mm_Vertical
SW1: SW_Nidec_CAS-120A1; TerminalBlock_Xinya_XY308-2.54-3P_1x03_P2.54mm_Horizontal
U1: ESP32-DEVKITC-32E; MODULE_ESP32-DEVKITC-32E; PARTREV 1.4

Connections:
GND: J1.1, U1.J2_14 (GND_J2_14), U1.J3_1 (GND_J3_1), U1.J3_7 (GND_J3_7)
unnamed: J1.2, SW1.2 (B)
unnamed: J2.1, U1.J2_8 (IO33)
unnamed: J2.2, U1.J2_7 (IO32)
unnamed: J3.1, U1.J3_2 (IO23)
unnamed: J3.2, U1.J3_8 (IO19)
unnamed: J4.1, U1.J3_4 (TXD0)
unnamed: J4.2, U1.J3_5 (RXD0)
unnamed: J5.1, U1.J3_3 (IO22)
unnamed: J5.2, U1.J3_6 (IO21)
unnamed: J6.1, U1.J3_15 (IO2)
unnamed: J6.2, U1.J3_16 (IO15)
unnamed: J7.1, U1.J2_10 (IO26)
unnamed: J7.2, U1.J2_9 (IO25)
unnamed: J8.1, U1.J2_12 (IO14)
unnamed: J8.2, U1.J2_11 (IO27)
unnamed: J9.1, U1.J2_15 (IO13)
unnamed: J9.2, U1.J2_13 (IO12)
unnamed: J10.1, U1.J2_6 (IO35)
unnamed: J10.2, U1.J2_5 (IO34)
unnamed: J11.1, U1.J2_4 (SENSOR_VN)
unnamed: J11.2, U1.J2_3 (SENSOR_VP)
unnamed: J12.1, U1.J3_11 (IO17)
unnamed: J12.2, U1.J3_12 (IO16)
unnamed: J12.3, U1.J3_13 (IO4)
unnamed: J13.1, U1.J3_9 (IO18)
unnamed: J13.2, U1.J3_10 (IO5)
unnamed: J13.3, U1.J3_14 (IO0)
unnamed: J14.1, U1.J2_1 (3V3)
unnamed: J15.1, U1.J2_2 (EN)
unnamed: J16.1, U1.J2_16 (SD2)
unnamed: J17.1, U1.J2_17 (SD3)
unnamed: J18.1, U1.J2_18 (CMD)
unnamed: J19.1, U1.J3_17 (SD1)
unnamed: J20.1, U1.J3_18 (SD0)
unnamed: J21.1, U1.J3_19 (CLK)
unnamed: SW1.3 (A), U1.J2_19 (EXT_5V)

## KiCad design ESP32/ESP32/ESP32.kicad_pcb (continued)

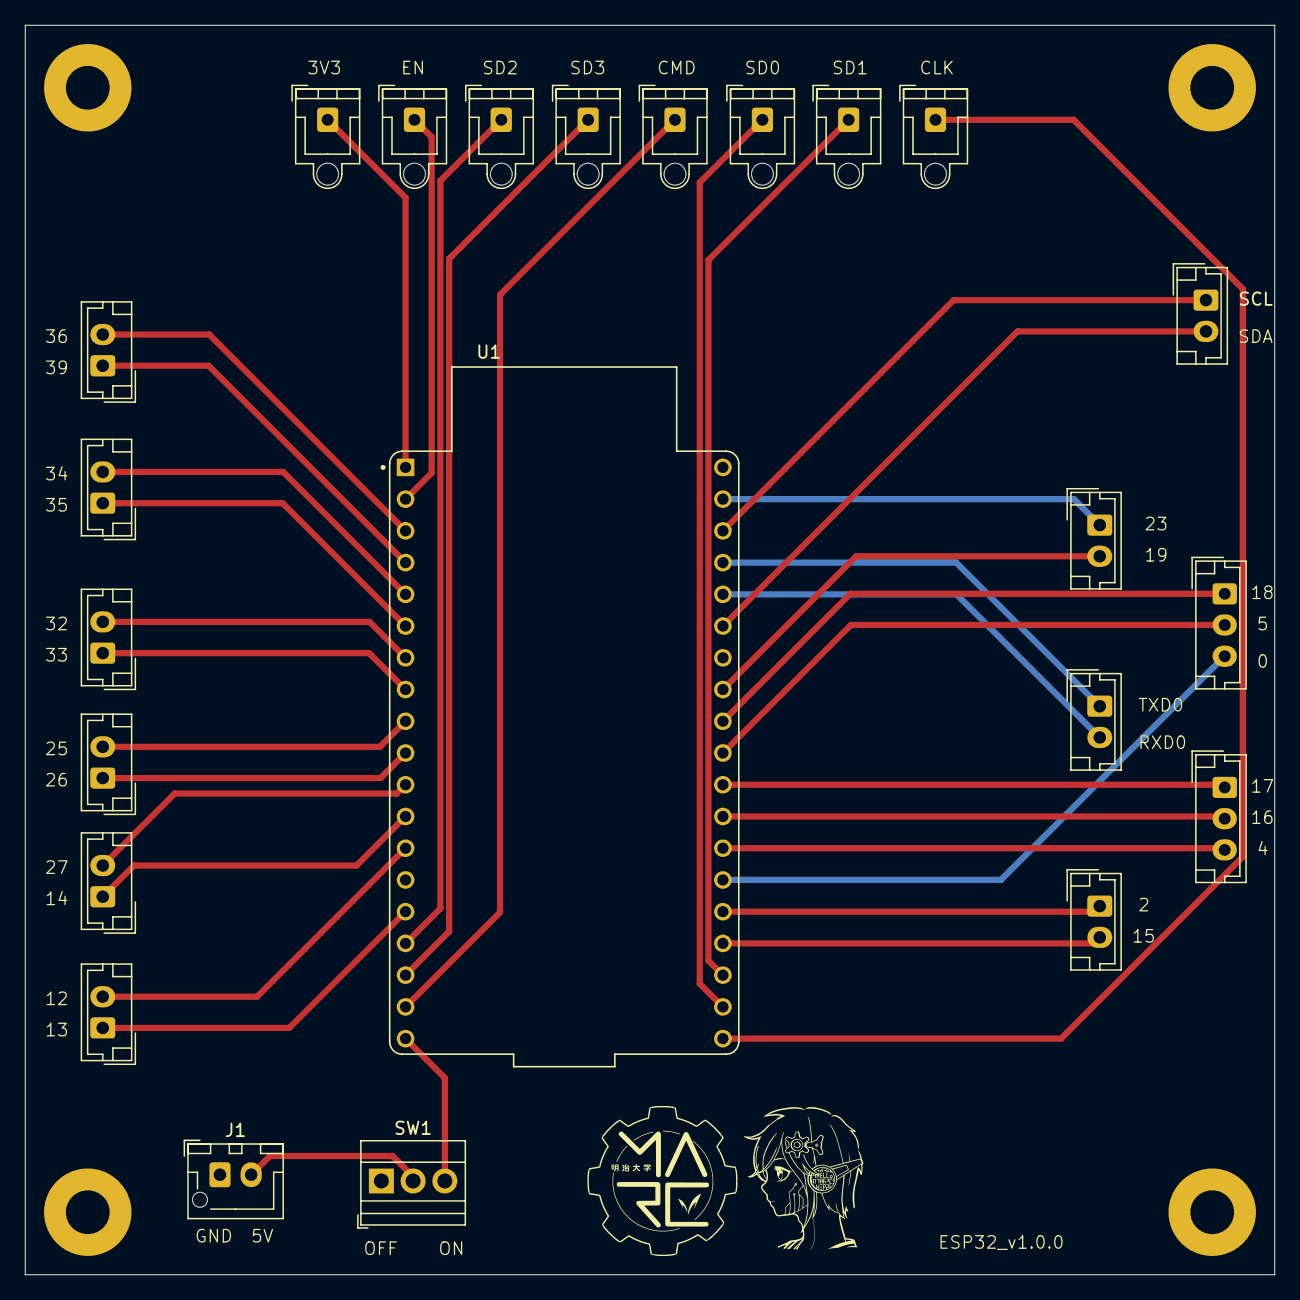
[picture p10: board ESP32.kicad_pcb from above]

Board: 2 copper layers, 100.0 x 100.0 mm, 23 parts (0 on the bottom side), 37 nets.

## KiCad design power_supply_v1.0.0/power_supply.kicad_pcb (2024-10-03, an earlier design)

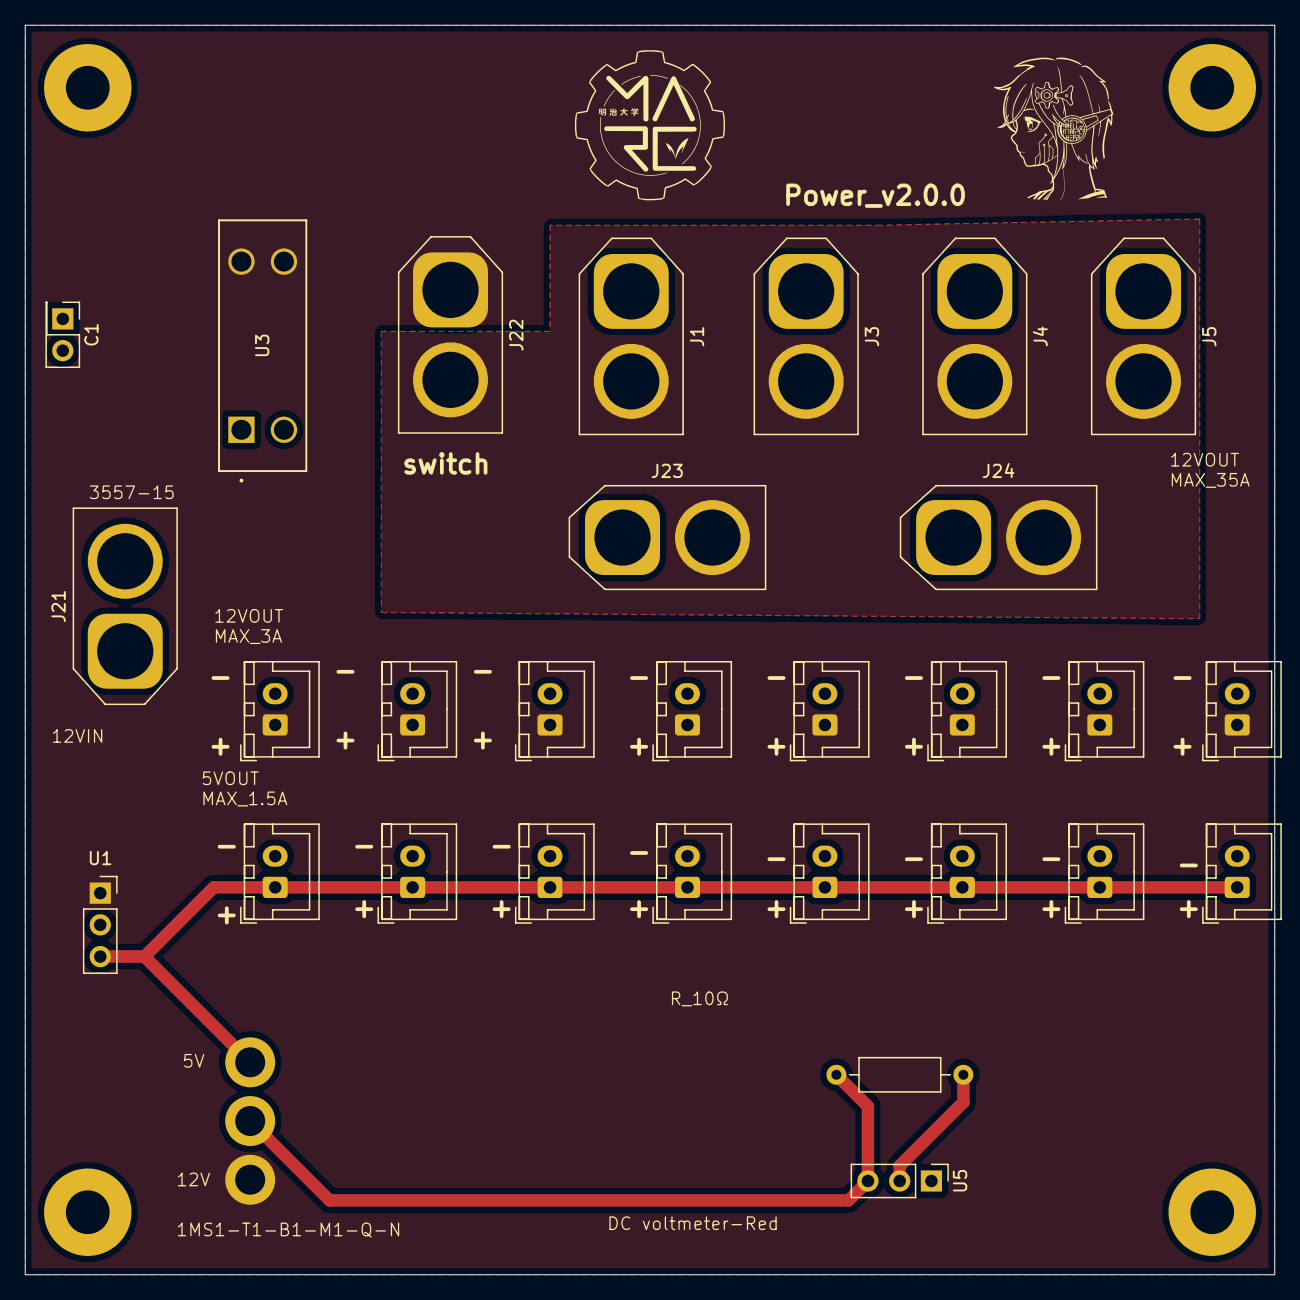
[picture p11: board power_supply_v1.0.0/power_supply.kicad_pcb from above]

Board: 2 copper layers, 100.0 x 100.0 mm, 30 parts (0 on the bottom side), 7 nets.

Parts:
C1: C; PinHeader_2x01_P2.54mm_Vertical
J1, J3, J4, J5, J23, J24: Conn_01x02_Socket; AMASS_XT60-F_1x02_P7.20mm_Vertical
J2, J6, J7, J8, J9, J10, J11, J12, J13, J14, J15, J16, J17, J18, J19, J20: Conn_01x02_Socket; JST_XH_B2B-XH-A_1x02_P2.50mm_Vertical
J21, J22: Conn_01x02_Pin; AMASS_XT60-F_1x02_P7.20mm_Vertical
R1: 10; R_Axial_DIN0207_L6.3mm_D2.5mm_P10.16mm_Horizontal
U1: PinSocket_1x03_P2.54mm_Vertical
U3: 3557-15_KEY
U4: 1MS1-T1-B1-M1-Q-N-S
U5: PinHeader_1x03_P2.54mm_Vertical

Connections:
+12V_1: C1.2, J21.2 (VCC), U3.1, U3.2
+12V_2: J6.1, J7.1, J8.1, J9.1, J10.1, J11.1, J12.1, J13.1, J22.1 (GND), U1.1 (VIN), U3.3, U3.4, U4.3
+12V_3: J1.2, J3.2, J4.2, J5.2, J22.2 (VCC), J23.2, J24.2
GND: C1.1, J1.1, J2.2, J3.1, J4.1, J5.1, J6.2, J7.2, J8.2, J9.2, J10.2, J11.2, J12.2, J13.2, J14.2, J15.2, J16.2, J17.2, J18.2, J19.2, J20.2, J21.1 (GND), J23.1, J24.1, U1.2 (GND), U5.1 (GND)
unnamed: J2.1, J14.1, J15.1, J16.1, J17.1, J18.1, J19.1, J20.1, U1.3 (VOUT), U4.1
unnamed: R1.1, U5.2
unnamed: R1.2, U4.2, U5.3 (OUT)

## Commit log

2024-10-05 名前変更
    [power_supply.kicad_pcb, power_supply.kicad_sch]
2024-10-08 設定ファイル
    フットプリントとシンボルデータ
2024-10-10 v1.1.0
    ・3端子レギュレータを追加
    ・ポリスイッチを追加
    ・配線を改良
    [ESP32_SMD.kicad_pcb, ESP32_SMD.kicad_sch]
2024-12-01 USB-cポートとシリアル変換を乗せた
    [ESP32_SMD.kicad_pcb, ESP32_SMD.kicad_sch]
